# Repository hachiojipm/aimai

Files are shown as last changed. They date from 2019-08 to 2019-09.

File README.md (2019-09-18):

(Japanese doc is here: [README_ja](./README_ja.md))



aimai is an "FM transceiver" name tag based on ESP32.

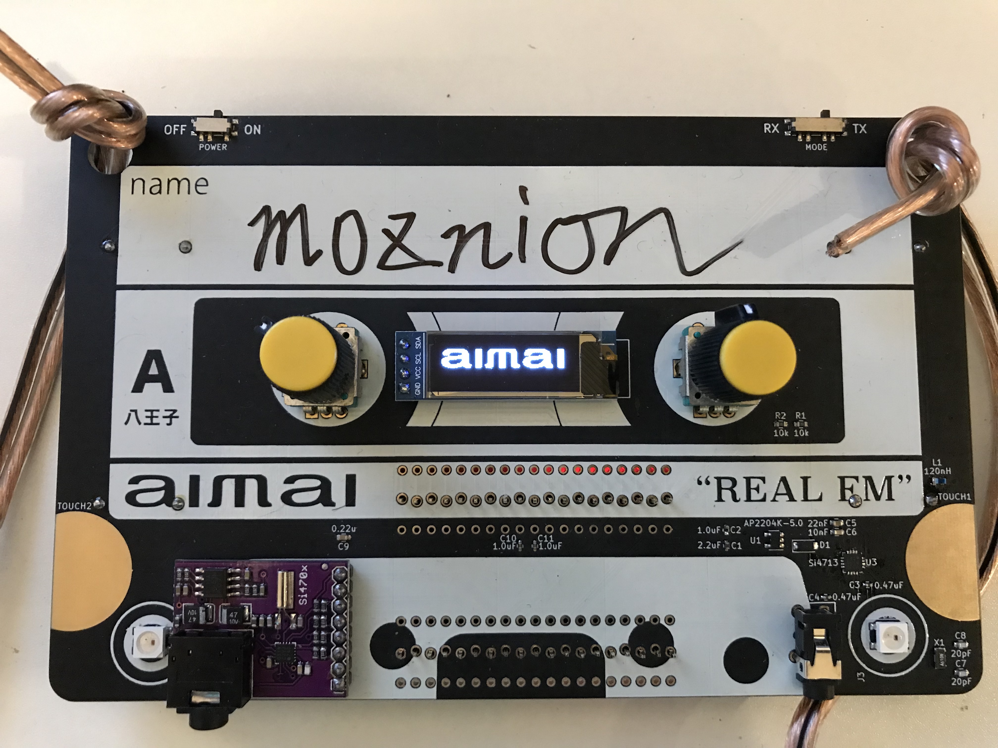
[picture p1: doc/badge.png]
badge


## Features

- FM radio receiver
  - Receiving sound
  - Receiving text data with [Radio Data System (RDS)](https://wikipedia.org/wiki/Radio_Data_System)
- FM radio transmitter
  - Transmitting sound
  - Transmitting text data with RDS
- Write your name on the board :)

## How to use

### Receiving (RX mode)

HIGHLY RECOMMENDED: it should be plugged earphones into the RX module's (purple one) phone jack because the earphones line works as an antenna. If not, it might be not able to receive text data through RDS.

- Turn on the device (by toggle switch at the top of left)
- Switch to the RX mode (by toggle switch at the top of right)
- The left knob: adjust the loudness
- The right knob: adjust the RX frequency
- OLED display: it shows received text data

### Transmitting (TX mode)

- Turn on the device (by toggle switch at the top of left)
- Switch to the TX mode (by toggle switch at the top of right)
- This mode transmits sound data through the TX module (the right one) line
- The left knob: RDS text input
  - Turn the knob, it chooses the characters
  - Click the knob, it decides a character
  - It needs to input 20 characters (hint: it supports the space character)
- The right knob: adjust the TX frequency
  - Click the knob, this is an escape key (i.e. leave from text input mode)
- OLED display: it shows transmitting text data

## How to build and upload the binary to ESP32 board

### Requirements

- [pythonz](https://github.com/saghul/pythonz)
- [direnv](https://github.com/direnv/direnv)

### How to bootstrap the project

```
$ make bootstrap
```

### How to build

```
$ make build
```

### How to upload

```
$ make upload
```

If you have something trouble, please edit the `upload_port` configuration on [platformio.ini](./platformio.ini).

## How to construct the board

A schematic and PCB data are here: [pcb](./pcb)

## Note

This project is optimized for Japan coverage. If you would like to use this device in countries other than Japan, you should modify the code of frequency band for `Si4703` and `Si4713`.

## Makers

- [uzulla](https://github.com/uzulla)
- [mackee](https://github.com/mackee)
- [moznion](https://github.com/moznion)

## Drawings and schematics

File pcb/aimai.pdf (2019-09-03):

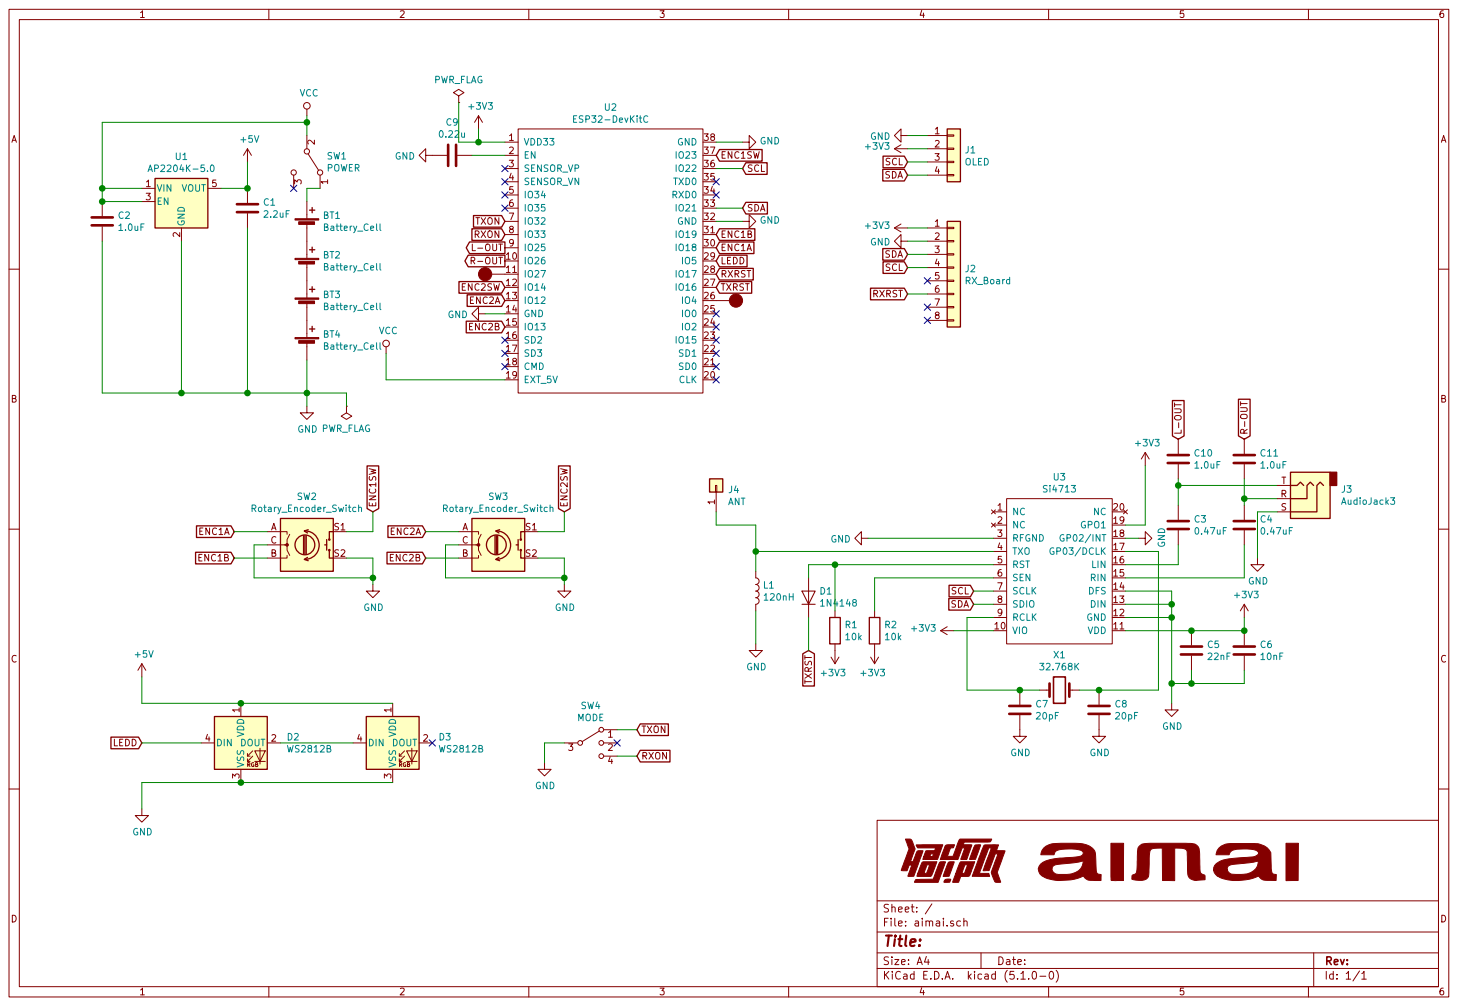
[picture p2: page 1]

Id: 1/1 Title: File: aimai.sch Sheet: /

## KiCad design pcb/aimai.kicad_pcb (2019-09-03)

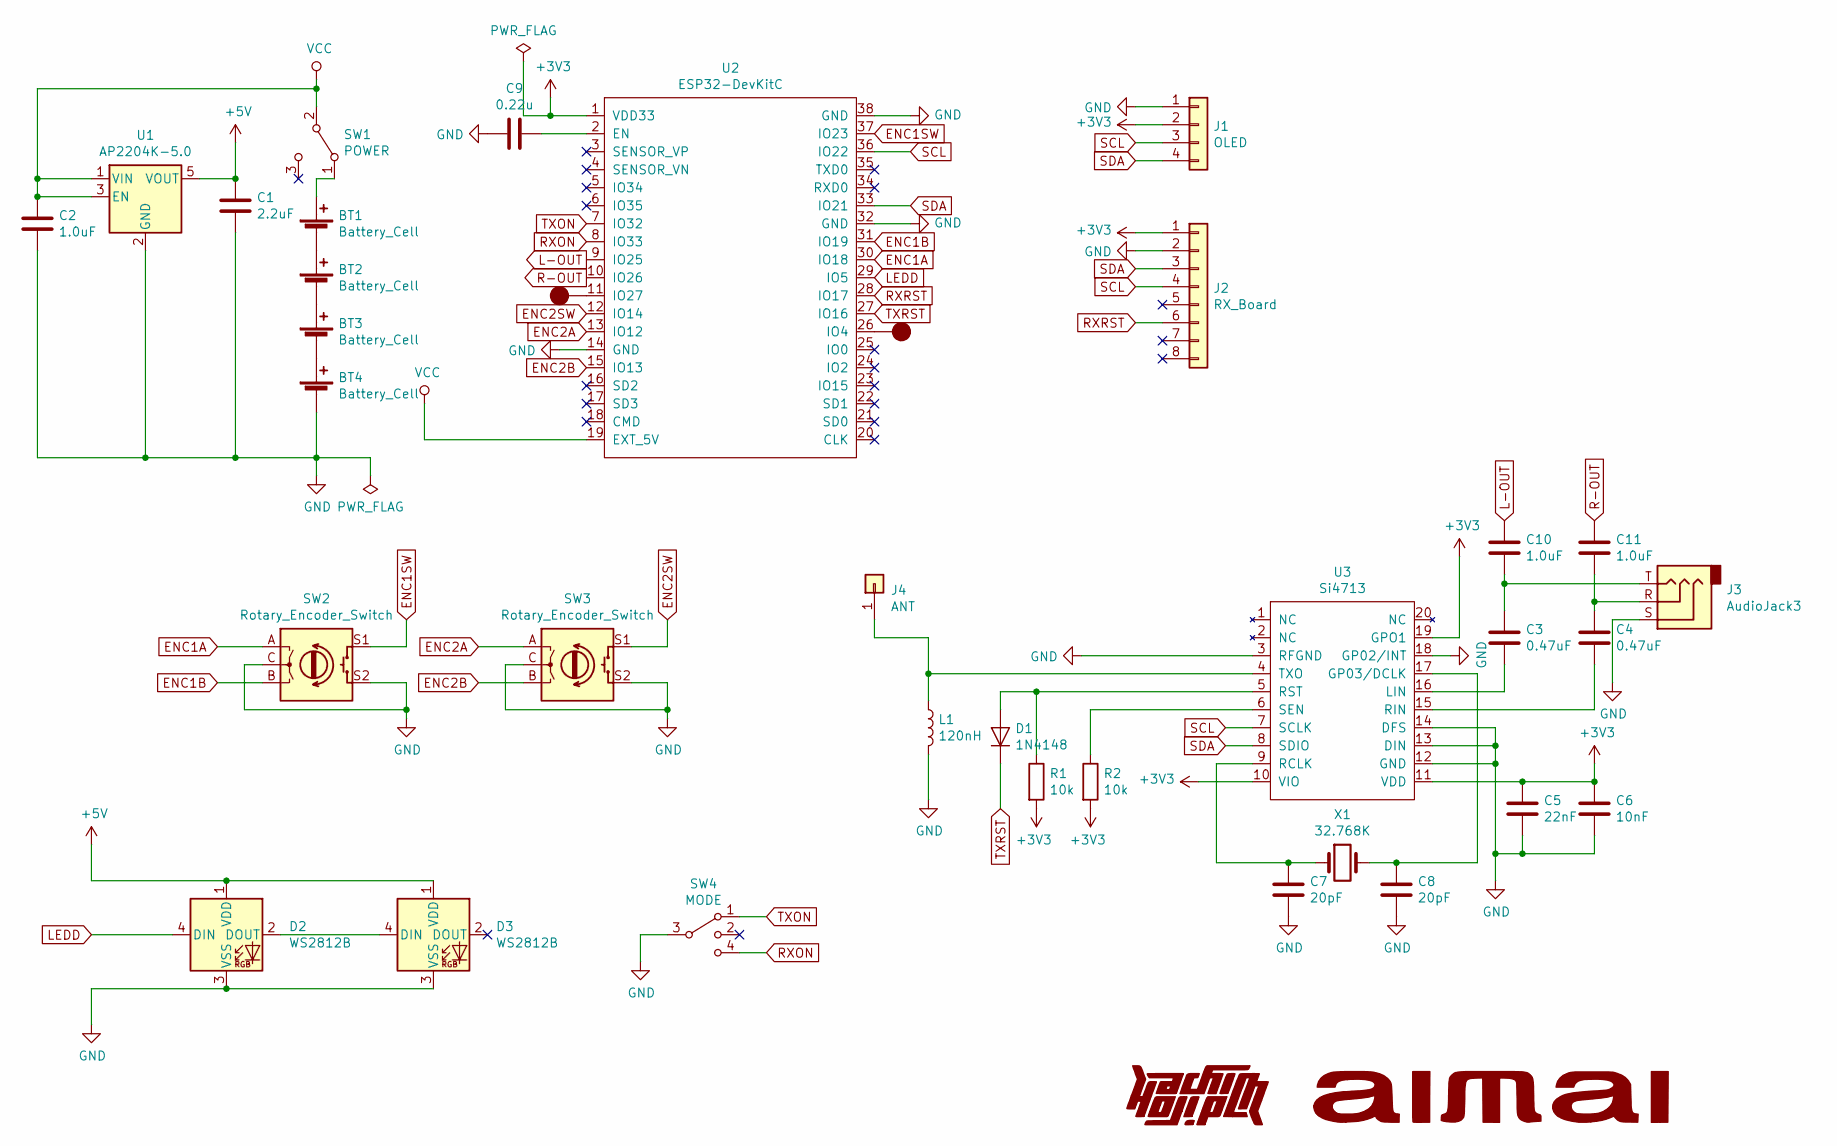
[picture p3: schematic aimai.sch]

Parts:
BT1, BT2, BT3, BT4: Battery_Cell; AAA-holder
C1: 2.2uF; C_0402
C2, C10, C11: 1.0uF; C_0402
C3, C4: 0.47uF; C_0402
C5: 22nF; C_0603
C6: 10nF; C_0603
C7, C8: 20pF; C_0603
C9: 0.22u; C_0603
D1: 1N4148; D_SOD-123
D2, D3: WS2812B; LED_WS2812B_PLCC4_5.0x5.0mm_P3.2mm
J1: OLED; SSD1306-128x32-Module
J2: RX_Board; Si4703-Module
J3: AudioJack3; ST-005-G
J4: ANT; Pin_Header_Straight_1x01_Pitch2.54mm
L1: 120nH; Neosid_Inductor_SM0603CG
R1, R2: 10k; C_0603
SW1: POWER; SW_SPDT_PCM12
SW2, SW3: Rotary_Encoder_Switch; RotaryEncoder_Alps_EC12E-Switch_Vertical_H20mm
SW4: MODE; SW_SP3T_PCM13
TOUCH1, TOUCH2: touchpad
U1: AP2204K-5.0; SOT-23-5
U2: ESP32-DevKitC
U3: Si4713; SiliconLabs_QFN-20-1EP_3x3mm_Pitch0.5mm
X1: 32.768K; Crystal_SMD_3215-2pin_3.2x1.5mm

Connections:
+3V3: C5.1, C6.1, J1.2, J2.1, R1.2, R2.2, U2.1 (VDD33), U3.10 (VIO), U3.11 (VDD), U3.19 (GPO1)
+5V: C1.1, D2.1 (VDD), D3.1 (VDD), U1.5 (VOUT)
ENC1A: SW2.A, U2.30 (IO18)
ENC1B: SW2.B, U2.31 (IO19)
ENC1SW: SW2.S1, U2.37 (IO23)
ENC2A: SW3.A, U2.13 (IO12)
ENC2B: SW3.B, U2.15 (IO13)
ENC2SW: SW3.S1, U2.12 (IO14)
GND: BT4.2 (-), C1.2, C2.2, C5.2, C6.2, C7.2, C8.2, C9.2, D2.3 (VSS), D3.3 (VSS), J1.1, J2.2, J3.S, L1.2, SW2.C, SW2.S2, SW3.C, SW3.S2, SW4.3, U1.2 (GND), U2.14 (GND), U2.32 (GND), U2.38 (GND), U3.3 (RFGND), U3.12 (GND), U3.13 (DIN), U3.14 (DFS), U3.18 (GP02/INT)
L-OUT: C10.1, U2.9 (IO25)
LEDD: D2.4 (DIN), U2.29 (IO5)
unnamed: BT1.1 (+), SW1.1 (A)
unnamed: BT1.2 (-), BT2.1 (+)
unnamed: BT2.2 (-), BT3.1 (+)
unnamed: BT3.2 (-), BT4.1 (+)
unnamed: C3.2, U3.16 (LIN)
unnamed: C4.2, U3.15 (RIN)
unnamed: C7.1, U3.9 (RCLK), X1.1
unnamed: C8.1, U3.17 (GP03/DCLK), X1.2
unnamed: C9.1, U2.2 (EN)
unnamed: C3.1, C10.2, J3.T
unnamed: C4.1, C11.2, J3.R
unnamed: D1.2 (A), R1.1, U3.5 (RST)
unnamed: D2.2 (DOUT), D3.4 (DIN)
unnamed: J4.1, L1.1, U3.4 (TXO)
unnamed: R2.1, U3.6 (SEN)
unnamed: TOUCH1.~, U2.26 (IO4)
unnamed: TOUCH2.~, U2.11 (IO27)
R-OUT: C11.1, U2.10 (IO26)
RXON: SW4.4, U2.8 (IO33)
RXRST: J2.6, U2.28 (IO17)
SCL: J1.3, J2.4, U2.36 (IO22), U3.7 (SCLK)
SDA: J1.4, J2.3, U2.33 (IO21), U3.8 (SDIO)
TXON: SW4.1, U2.7 (IO32)
TXRST: D1.1 (K), U2.27 (IO16)
VCC: C2.1, SW1.2 (B), U1.1 (VIN), U1.3 (EN), U2.19 (EXT_5V)

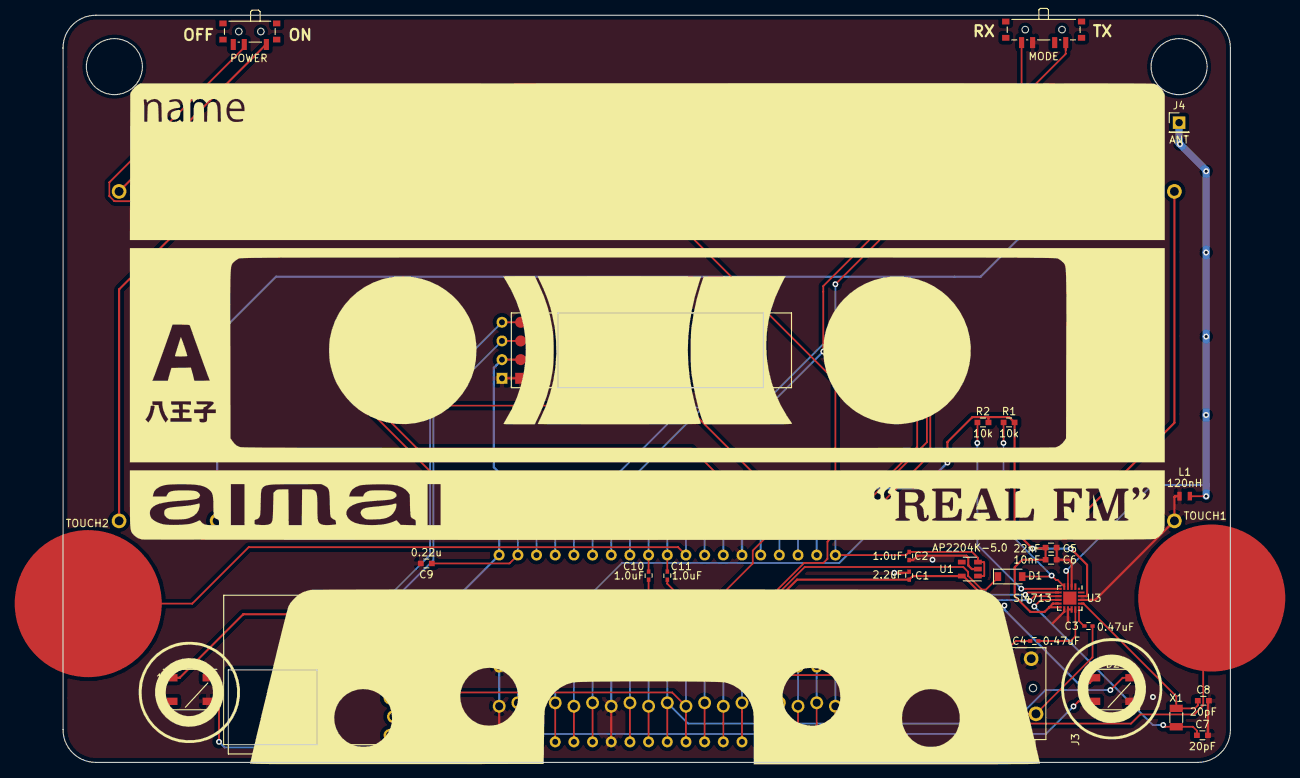
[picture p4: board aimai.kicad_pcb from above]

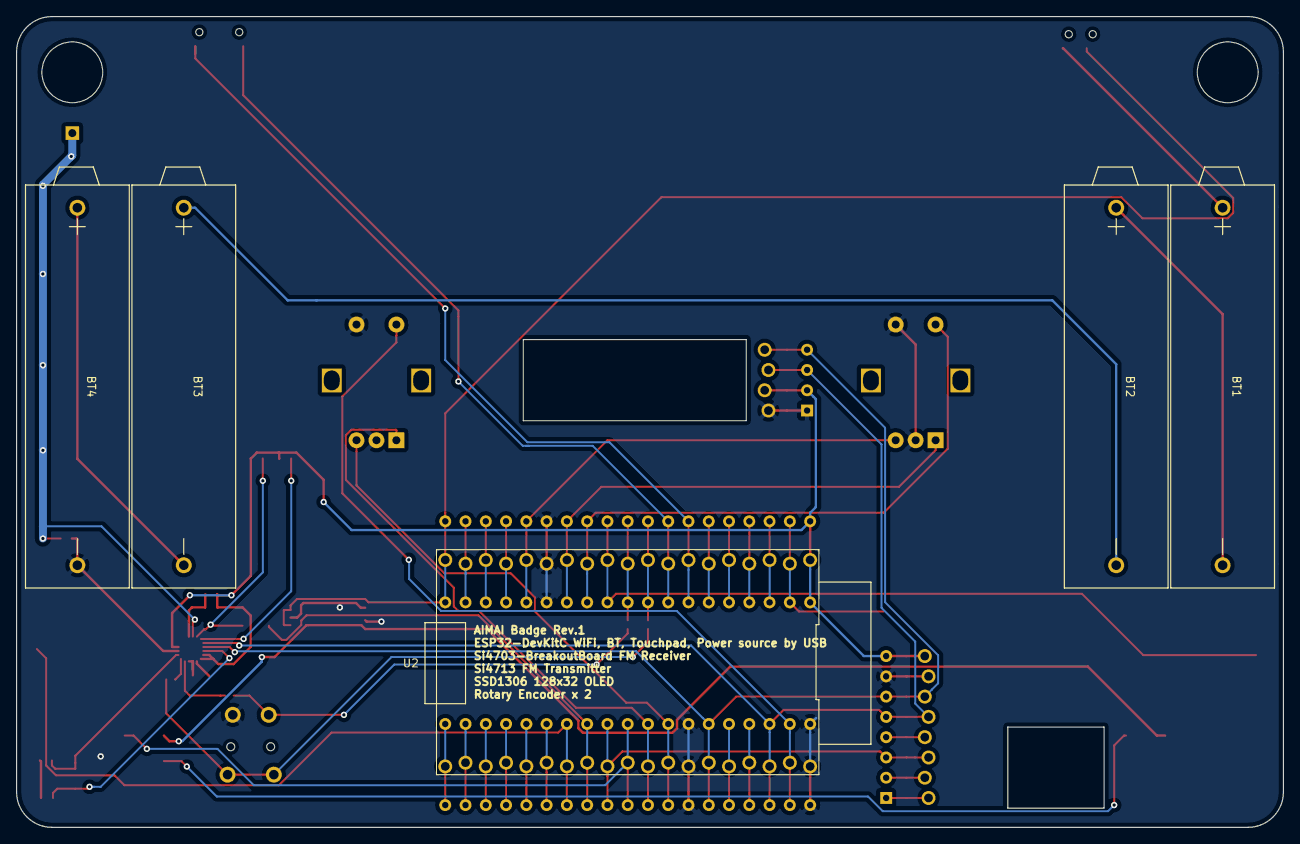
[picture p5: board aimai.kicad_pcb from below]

Board: 2 copper layers, 158.8 x 101.6 mm, 37 parts (6 on the bottom side), 36 nets.

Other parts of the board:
G1: LOGO; awia_silk
G2: LOGO; awia_silk_back

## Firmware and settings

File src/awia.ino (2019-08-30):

#include "awia.h"
#include "view.h"
#include <SparkFunSi4703.h>
#include <Adafruit_Si4713.h>
#include <esp_attr.h>
#include <Adafruit_SSD1306.h>
#include <Wire.h>
#include <esp32-hal-log.h>
#include <freertos/task.h>
#include <esp32-hal-timer.h>
#include <EEPROM.h>

View view;
Si4703_Breakout rx(RX_RST_PIN, SDA_PIN, SCL_PIN, UNUSED);
Adafruit_Si4713 tx(TX_RST_PIN);

volatile int16_t rxVol = 0; // TODO load init value from the nonvolatile memory
volatile int16_t rxFreq = JP_MINIMUM_FM_MHZ; // TODO load init value from the nonvolatile memory
volatile int16_t txFreq = JP_MINIMUM_FM_MHZ; // TODO load init value from the nonvolatile memory

volatile bool isRXRDSReading = false;

xTaskHandle xReadRDSTaskHandler;
char rdsBuff[RDS_TEXT_LENGTH + 1]; // thi param is used by both of the state (i.e. rx and tx)

void setup() {
    Serial.begin(115200);
    while (!Serial);
    log_i("setup...");

    view.begin();
    view.displayLogo();

    EEPROM.begin(EEPROM_LENGTH);

    pinMode(RIGHT_ENC_PIN_A, INPUT_PULLUP);
    pinMode(RIGHT_ENC_PIN_B, INPUT_PULLUP);
    pinMode(RIGHT_ENC_SW_PIN, INPUT_PULLUP);
    pinMode(LEFT_ENC_PIN_A, INPUT_PULLUP);
    pinMode(LEFT_ENC_PIN_B, INPUT_PULLUP);
    pinMode(LEFT_ENC_SW_PIN, INPUT_PULLUP);

    pinMode(RX_MODE_PIN, INPUT_PULLUP);
    detachInterrupt(RX_MODE_PIN);
    attachInterrupt(RX_MODE_PIN, loadActionMode, CHANGE);

    pinMode(TX_MODE_PIN, INPUT_PULLUP);
    detachInterrupt(TX_MODE_PIN);
    attachInterrupt(TX_MODE_PIN, loadActionMode, CHANGE);

    xTaskCreatePinnedToCore(readRDSPeriodically, TASK_READ_RDS_PERIODICALLY, 4096, NULL, READ_RDS_TASK_PRIORITY,
                            &xReadRDSTaskHandler, READ_RDS_TASK_CPU_NO);
    loadActionMode();
}

void initRx() {
    detachInterrupt(RIGHT_ENC_PIN_A);
    attachInterrupt(RIGHT_ENC_PIN_A, changeRxVolume, CHANGE);
    detachInterrupt(RIGHT_ENC_PIN_B);
    attachInterrupt(RIGHT_ENC_PIN_B, changeRxVolume, CHANGE);

    detachInterrupt(LEFT_ENC_PIN_A);
    attachInterrupt(LEFT_ENC_PIN_A, changeRxFreq, CHANGE);
    detachInterrupt(LEFT_ENC_PIN_B);
    attachInterrupt(LEFT_ENC_PIN_B, changeRxFreq, CHANGE);

    rx.powerOn();
    rx.setChannel(0);
    rx.setVolume(0);

    vTaskResume(xReadRDSTaskHandler);
}

char txRDSText[RDS_TEXT_LENGTH + 1] = {
        '(', 'e', 'm', 'p', 't', 'y', ')', ' ', ' ', ' ', ' ', ' ', ' ', ' ', ' ', ' ', ' ', ' ', ' ', ' ', '\0'
};
volatile int txRDSBuffCursor = 0;

void initTx() {
    detachInterrupt(RIGHT_ENC_PIN_A);
    attachInterrupt(RIGHT_ENC_PIN_A, editRDSText, CHANGE);
    detachInterrupt(RIGHT_ENC_PIN_B);
    attachInterrupt(RIGHT_ENC_PIN_B, editRDSText, CHANGE);

    detachInterrupt(RIGHT_ENC_SW_PIN);
    attachInterrupt(RIGHT_ENC_SW_PIN, enterRDSTextCharacter, FALLING);

    detachInterrupt(LEFT_ENC_PIN_A);
    attachInterrupt(LEFT_ENC_PIN_A, changeTxFreq, CHANGE);
    detachInterrupt(LEFT_ENC_PIN_B);
    attachInterrupt(LEFT_ENC_PIN_B, changeTxFreq, CHANGE);
    detachInterrupt(LEFT_ENC_SW_PIN);
    attachInterrupt(LEFT_ENC_SW_PIN, escapeRDSTextEditing, FALLING);

    tx.begin();
    tx.setTXpower(TX_POWER);

    tx.beginRDS();
    tx.setRDSstation(STATION_NAME);
    uint8_t isTxRDSTextWrote;
    EEPROM.get(EEPROM_IS_TX_RDS_WROTE_ADDR, isTxRDSTextWrote);
    if (isTxRDSTextWrote == EEPROM_IS_TX_RDS_WROTE_MARKER) {
        char tmpTxRDSText[RDS_TEXT_LENGTH + 1];
        for (int i = 0; i < RDS_TEXT_LENGTH + 1; i++) {
            char c;
            EEPROM.get(i + EEPROM_TX_RDS_TEXT_ADDR_BEGIN, c);
            tmpTxRDSText[i] = c;
        }
        strcpy(txRDSText, tmpTxRDSText);
    }
    tx.setRDSbuffer(txRDSText);
}

volatile bool txRDSTextChanged = false;

volatile bool doDisplayRXRDS = false;

void tickRXRDSDisplay() {
    doDisplayRXRDS = true;
}

void rxLoop(void *arg) {
    // TODO read from nonvolatile memory
    rxFreq = 761;
    int mainLoopRxFreq = rxFreq;
    rx.setChannel(mainLoopRxFreq);
    rxVol = 3;
    int mainLoopRxVol = rxVol;
    rx.setVolume(mainLoopRxVol);

    hw_timer_t *rxRDSDisplayTicker = nullptr;
    rxRDSDisplayTicker = timerBegin(0, 80, true);
    timerAttachInterrupt(rxRDSDisplayTicker, &tickRXRDSDisplay, true);
    timerAlarmWrite(rxRDSDisplayTicker, 1000000, true);
    timerAlarmEnable(rxRDSDisplayTicker);

    while (true) {
        bool isDisplayedRXCtrl = false;
        if (mainLoopRxFreq != rxFreq) {
            rx.setChannel(rxFreq);
            mainLoopRxFreq = rxFreq;
            view.displayRxFreq(rxFreq);
            isDisplayedRXCtrl = true;
        }

        if (mainLoopRxVol != rxVol) {
            rx.setVolume(rxVol);
            mainLoopRxVol = rxVol;
            view.displayVol(rxVol);
            isDisplayedRXCtrl = true;
        }

        if (isDisplayedRXCtrl) {
            doDisplayRXRDS = false;
            timerEnd(rxRDSDisplayTicker);
            rxRDSDisplayTicker = timerBegin(0, 80, true);
            timerAttachInterrupt(rxRDSDisplayTicker, &tickRXRDSDisplay, true);
            timerAlarmWrite(rxRDSDisplayTicker, 300000, true);
            timerAlarmEnable(rxRDSDisplayTicker);
            delay(50);
        }

        if (doDisplayRXRDS && !isRXRDSReading) {
            view.displayRxRDSTextAsMarquee(rdsBuff);
        }
    }
}

volatile bool rdsTextEntering = false;
volatile bool rdsEditing = false;

#define RUNES_NUM 44
char runes[RUNES_NUM] = {
        ' ',
        'a', 'b', 'c', 'd', 'e', 'f', 'g', 'h', 'i', 'j', 'k', 'l', 'm',
        'n', 'o', 'p', 'q', 'r', 's', 't', 'u', 'v', 'w', 'x', 'y', 'z',
        '0', '1', '2', '3', '4', '5', '6', '7', '8', '9', '.', ',', '-',
        '_', '@', '(', ')'
};
volatile int16_t textInputCursor = 0;

volatile bool doDisplayTxRDS = false;

void tickTxRDSDisplay() {
    doDisplayTxRDS = true;
}

void txLoop(void *arg) {
    // TODO read from nonvolatile memory
    txFreq = JP_MINIMUM_FM_MHZ;
    int mainLoopTxFreq = txFreq;
    tx.tuneFM(txFreq * 10);

    hw_timer_t *txRDSDisplayTicker = nullptr;
    txRDSDisplayTicker = timerBegin(0, 80, true);
    timerAttachInterrupt(txRDSDisplayTicker, &tickTxRDSDisplay, true);
    timerAlarmWrite(txRDSDisplayTicker, 1000000, true);
    timerAlarmEnable(txRDSDisplayTicker);

    while (true) {
        if (mainLoopTxFreq != txFreq) {
            tx.tuneFM(txFreq * 10);
            mainLoopTxFreq = txFreq;
            view.displayTxFreq(txFreq);

            doDisplayTxRDS = false;
            timerEnd(txRDSDisplayTicker);
            txRDSDisplayTicker = timerBegin(0, 80, true);
            timerAttachInterrupt(txRDSDisplayTicker, &tickTxRDSDisplay, true);
            timerAlarmWrite(txRDSDisplayTicker, 300000, true);
            timerAlarmEnable(txRDSDisplayTicker);
            delay(50);
        }

        if (txRDSTextChanged) {
            tx.setRDSbuffer(txRDSText);
            EEPROM.put(EEPROM_IS_TX_RDS_WROTE_ADDR, EEPROM_IS_TX_RDS_WROTE_MARKER);
            for (int i = 0; i < RDS_TEXT_LENGTH + 1; i++) {
                EEPROM.put(EEPROM_TX_RDS_TEXT_ADDR_BEGIN + i, txRDSText[i]);
            }
            EEPROM.commit();
            txRDSTextChanged = false;
        }

        // workaround for avoiding chattering
        if (rdsTextEntering) {
            delay(200);
            rdsTextEntering = false;
        }

        if (rdsEditing) {
            rdsBuff[txRDSBuffCursor] = runes[textInputCursor];
            view.displayTxRDSTextForInput(rdsBuff);
            delay(100);
        } else if (doDisplayTxRDS) {
            view.displayTxRDSTextAsMarquee(txRDSText);
        }
    }
}

void nopLoop(void *arg) {
    while (true) {
    }
}

const static unsigned char defaultRXRDSText[RDS_TEXT_LENGTH + 1] = {
        '<', 'n', 'o', ' ', 'r', 'd', 's', ' ', 'd', 'a',
        't', 'a', '>', ' ', ' ', ' ', ' ', ' ', ' ', ' ',
        '\0'
};

void readRDSPeriodically(void *arg) {
    delay(1000); // if this delay doesn't exist, the RX procedure be stuck
    while (true) {
        log_d("read RDS");
        isRXRDSReading = true;
        rx.readRDS(rdsBuff, RDS_READING_TIMEOUT_MILLIS);
        log_d("RDS buff: %s", rdsBuff);
        if (rdsBuff[0] == '\0') {
            memcpy(rdsBuff, defaultRXRDSText, RDS_TEXT_LENGTH + 1);
        }
        isRXRDSReading = false;
        delay(RDS_READING_PERIOD_MILLIS);
    }
}


volatile byte posForRxVol;

void changeRxVolume() {
    EncCountStatus encStatus = _readEncCountStatus(RIGHT, &posForRxVol, &rxVol);
    if (encStatus.currentCnt != encStatus.previousCnt) {
        if (encStatus.currentCnt <= 0) {
            rxVol = 0;
        } else if (encStatus.currentCnt > 15) {
            rxVol = 15;
        }
        log_d("Rx vol: %d", rxVol);
    }
}

volatile byte posForRxFreq;

void changeRxFreq() {
    EncCountStatus encStatus = _readEncCountStatus(LEFT, &posForRxFreq, &rxFreq);
    if (encStatus.currentCnt != encStatus.previousCnt) {
        if (encStatus.currentCnt < JP_MINIMUM_FM_MHZ) {
            rxFreq = JP_MAXIMUM_FM_MHZ;
        } else if (encStatus.currentCnt > JP_MAXIMUM_FM_MHZ) {
            rxFreq = JP_MINIMUM_FM_MHZ;
        }
        log_d("Rx freq: %fMHz", rxFreq / 10.0);
    }
}

volatile byte posForTxFreq;

void changeTxFreq() {
    EncCountStatus encStatus = _readEncCountStatus(LEFT, &posForTxFreq, &txFreq);
    if (encStatus.currentCnt != encStatus.previousCnt) {
        if (encStatus.currentCnt < JP_MINIMUM_FM_MHZ) {
            txFreq = JP_MAXIMUM_FM_MHZ;
        } else if (encStatus.currentCnt > JP_MAXIMUM_FM_MHZ) {
            txFreq = JP_MINIMUM_FM_MHZ;
        }
        log_d("Tx freq: %fMHz", txFreq / 10.0);
    }
}

volatile byte posForTextInput;

void editRDSText() {
    if (!rdsEditing) {
        rdsEditing = true;
        txRDSBuffCursor = 0;
        memset(rdsBuff, '\0', RDS_TEXT_LENGTH + 1);
    }

    EncCountStatus encStatus = _readEncCountStatus(RIGHT, &posForTextInput, &textInputCursor);
    if (encStatus.currentCnt != encStatus.previousCnt) {
        if (encStatus.currentCnt < 0) { // alignment
            textInputCursor = RUNES_NUM - 1;
        } else if (encStatus.currentCnt > (RUNES_NUM - 1)) {
            textInputCursor = 0;
        }
    }
}

void enterRDSTextCharacter() {
    if (rdsTextEntering || !rdsEditing) {
        return;
    }
    rdsTextEntering = true;
    log_d("char: %c", runes[textInputCursor]);
    rdsBuff[txRDSBuffCursor] = runes[textInputCursor];
    txRDSBuffCursor++;
    if (txRDSBuffCursor >= RDS_TEXT_LENGTH) {
        memcpy(txRDSText, rdsBuff, RDS_TEXT_LENGTH);
        log_d("RDS text: %s", txRDSText);
        txRDSTextChanged = true;
        escapeRDSTextEditing();
    }
}

void escapeRDSTextEditing() {
    rdsEditing = false;
}

EncCountStatus _readEncCountStatus(EncSide encSide, volatile byte *pos, volatile int16_t *cnt) {
    byte current;
    switch (encSide) {
        case LEFT:
            current = (!digitalRead(LEFT_ENC_PIN_B) << 1) + !digitalRead(LEFT_ENC_PIN_A);
            break;
        case RIGHT:
            current = (!digitalRead(RIGHT_ENC_PIN_B) << 1) + !digitalRead(RIGHT_ENC_PIN_A);
            break;
        default:
            // absolutely unreachable
            log_e("[ERROR] unexpected enc side has come: %s", encSide);
            return {0, 0};
    }

    byte previous = *pos & 0b11;
    byte direction = (*pos & 0b00110000) >> 4;

    if (current == 3) current = 2;
    else if (current == 2) current = 3;

    int16_t previousCnt = *cnt;

    if (current != previous) {
        if (direction == 0) {
            if (current == 0b01 || current == 0b11) {
                direction = current;
            }
        } else {
            if (current == 0b00) {
                if (direction == 0b01 && previous == 0b11) {
                    (*cnt)++;
                } else if (direction == 0b11 && previous == 0b01) {
                    (*cnt)--;
                }
                direction = 0b00;
            }
        }
        *pos = (direction << 4) + (previous << 2) + current;
    }

    EncCountStatus encStatus = {previousCnt, *cnt};
    return encStatus;
}

void inactivateRx() {
    pinMode(RX_RST_PIN, OUTPUT);
    digitalWrite(RX_RST_PIN, HIGH);
    delay(10);
    digitalWrite(RX_RST_PIN, LOW);
    delay(10);
    digitalWrite(RX_RST_PIN, HIGH);

    vTaskSuspend(xReadRDSTaskHandler);
}

void inactivateTx() {
    tx.reset();
}

void loadActionMode() {
    int rx = digitalRead(RX_MODE_PIN);
    int tx = digitalRead(TX_MODE_PIN);
    if (rx == HIGH && tx == LOW) {
        log_i("Tx mode");
        inactivateRx();
        initTx();
        xTaskCreatePinnedToCore(txLoop, TASK_MAIN, 4096, NULL, MAIN_TASK_PRIORITY, NULL, MAIN_TASK_CPU_NO);
        return;
    }

    if (tx == HIGH && rx == LOW) {
        log_i("Rx mode");
        inactivateTx();
        initRx();
        xTaskCreatePinnedToCore(rxLoop, TASK_MAIN, 4096, NULL, MAIN_TASK_PRIORITY, NULL, MAIN_TASK_CPU_NO);
        return;
    }

    // both of the mode pins are 0 or 1, this handles it as NOP mode
    log_i("NOP mode");
    inactivateTx();
    inactivateRx();
    xTaskCreatePinnedToCore(nopLoop, TASK_MAIN, 4096, NULL, MAIN_TASK_PRIORITY, NULL, MAIN_TASK_CPU_NO);
}

void loop() {
}

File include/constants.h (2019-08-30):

#ifndef _AWIA_CONSTANTS_INC_GUARDS_H_
#define _AWIA_CONSTANTS_INC_GUARDS_H_

#define STATION_NAME "JOHN DOE"

#define UNUSED -1

#define SDA_PIN 21
#define SCL_PIN 22
#define RX_RST_PIN 17
#define TX_RST_PIN 16

#define RX_MODE_PIN 33
#define TX_MODE_PIN 32

#define LEFT_ENC_SW_PIN 23
#define LEFT_ENC_PIN_A 18
#define LEFT_ENC_PIN_B 19
#define RIGHT_ENC_SW_PIN 14
#define RIGHT_ENC_PIN_A 12
#define RIGHT_ENC_PIN_B 13

#define JP_MINIMUM_FM_MHZ 761
#define JP_MAXIMUM_FM_MHZ 949
#define TX_POWER 115
#define RDS_TEXT_LENGTH 20
#define RDS_READING_TIMEOUT_MILLIS 3000
#define RDS_READING_PERIOD_MILLIS 15000

#define OLED_ADDR 0x3c
#define OLED_TEXT_LEN_BY_ONE_LINE 11
#define SCREEN_WIDTH 128
#define SCREEN_HEIGHT 32
#define LOGO_WIDTH 128
#define LOGO_HEIGHT 32

#define MAIN_TASK_CPU_NO 1
#define READ_RDS_TASK_CPU_NO 0
#define MAIN_TASK_PRIORITY 1 | portPRIVILEGE_BIT
#define READ_RDS_TASK_PRIORITY 2 | portPRIVILEGE_BIT
#define TASK_READ_RDS_PERIODICALLY "read_rds_periodically"
#define TASK_MAIN "main"

#define EEPROM_LENGTH 1024
#define EEPROM_IS_TX_RDS_WROTE_ADDR 0
#define EEPROM_TX_RDS_TEXT_ADDR_BEGIN 1

#define EEPROM_IS_TX_RDS_WROTE_MARKER 0x0a

#endif //_AWIA_CONSTANTS_INC_GUARDS_H_

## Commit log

2019-08-12 Adjust rotary pin number
2019-08-12 Add rotary encoder's sw pin definitions
2019-08-12 Support action mode switching
2019-08-12 Invert the position of the rotary switches
    [awia.ino]
2019-08-13 Show splash text on the LED
2019-08-20 Fix to use the CORRECT SSD1306 library
    [awia.ino]
2019-08-21 Fix the function name
    [awia.ino]
2019-08-28 Add workaround for chattering on RDS text entering
    [awia.ino]
2019-08-29 Reduce the risk of crashing
    [awia.ino]
2019-09-03 add schematics, pcb
    [aimai.kicad_pcb, aimai.sch]
